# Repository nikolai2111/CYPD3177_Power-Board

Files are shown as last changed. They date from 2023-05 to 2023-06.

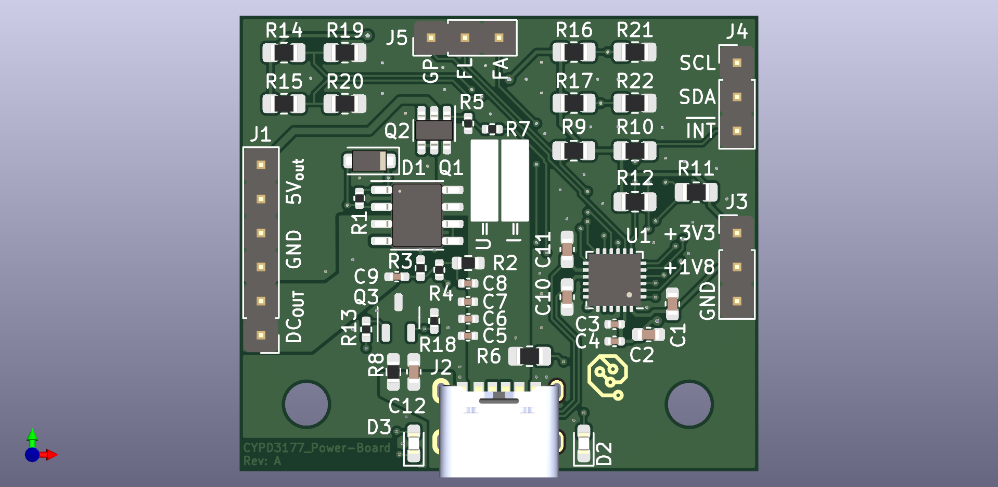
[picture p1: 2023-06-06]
PCB_Top_A.png

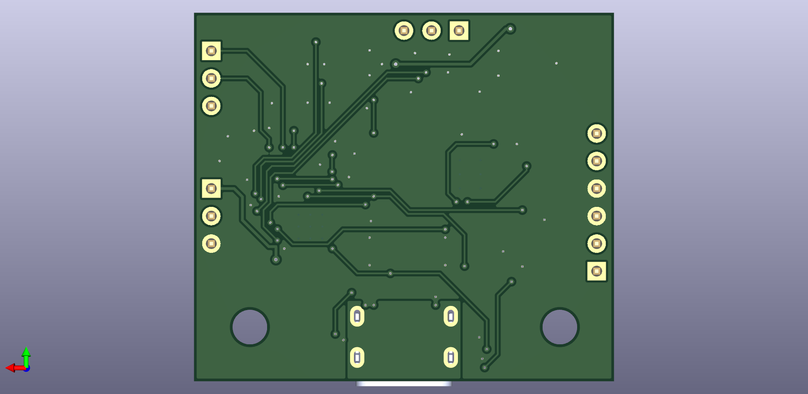
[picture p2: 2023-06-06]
PCB_Bottom_C.png

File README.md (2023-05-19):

# CYPD3177_Power-Board <!-- omit from toc -->

## Content <!-- omit from toc -->
- [1. Description](#1-description)
- [2. Folder structure](#2-folder-structure)
- [3. Usage](#3-usage)
- [4. License](#4-license)

## 1. Description
TBC: Easy to use and programmable power board for powering your electronics with up to 100 watts of power.

## 2. Folder structure
TBC

## 3. Usage
Add instructions and examples here.

## 4. License
The hardware and its documentation is licensed under the CERN-OHL-P licence, which can be found [here](LICENSE).

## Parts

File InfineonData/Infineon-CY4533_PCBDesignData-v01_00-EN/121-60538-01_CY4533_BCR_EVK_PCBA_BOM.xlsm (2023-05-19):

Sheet: Revision History
CYPRESS SEMICONDUCTOR © 2017
Revision | Date | Description | Prepared By | Approved By
1 | 2018-09-17 | First version of CY4533 BOM | KUMR | PDS
 |  |  |  |  | a

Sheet: PCBA BOM
 |  |  |  |  | CYPRESS SEMICONDUCTOR © 2018-2019
 |  |  |  |  | TITLE | CY4533 BCR Evaluation Kit
 |  |  |  |  | PCA Number & Revision | 121-60538-01 | Rev 02
 |  |  |  |  | Schematics Number & Revision | 630-60538-01 | Rev 02
 |  |  |  |  | DATE | 2019-03-27
 |  |  |  |  | BOM REVISION | Rev 03
 |  |  |  |  | ROHS Compliance | Required
 |  |  |  |  | UL Compliance | Required
# | Cypress Part # | Qty | Reference | Value | Description | Manufacturer | Mfr Part # | Alternate Manufacturer | Alternate Mfr Part #
1 |  | 2 | C1,C4 | 1uF | CAP CER 1UF 16V X7R 0603 | KEMET | C0603C105K4RACTU
2 |  | 2 | C2,C3 | 0.1uF | CAP CER 0.1UF 10V X7R 0402 | AVX Corporation | 0402ZC104KAT2A
3 |  | 2 | C5,C6 | 390pF | CAP CER 390PF 50V 5% X7R 0603 | Kemet | C0603C391J5RACTU
4 |  | 1 | C7 | 3.3uF | CAP CER 3.3UF 50V X7R 1210 | KEMET | C1210C335K5RACAUTO
5 |  | 1 | C8 | 1uF | CAP CER 1UF 35V X5R 0402 | Samsung Electro-Mechanics | CL05A105KL5NRNC
6 |  | 1 | D1 | RED | LED RED CLEAR 0603 SMD | Lite-On Inc. | LTST-C190EKT
7 |  | 1 | D2 | GREEN | LED GREENCLEAR 0603 SMD | Lite-On Inc. | LTST-C190GKT
8 |  | 1 | D3 | NZH10C-115 | DIODE ZENER 10V 500MW SOD123F | Nexperia USA Inc. | NZH10C,115
9 |  | 1 | J1 | 8x1 RECP | CONN HEADER .100 SINGL STR 8POS | Sullins Connector Solutions | S9691E-08
10 |  | 1 | J2 | USB-PD_TYPE-C | CU18 USB Type-C Receptacle Connector | CviLux Corporation | CU1816SAH1BA0R001-LF-CUS
11 |  | 1 | J3 | TERMINAL_BLOCK | TERMINAL BLOCK 5MM VERT 2POS PCB | On Shore | OSTTC020162
12 |  | 1 | Q1 | IRF9358TRPBF | MOSFET 2P-CH 30V 9.2A 8SOIC | Infineon Technologies | IRF9358TRPBF
13 |  | 1 | Q3 | BSL308PE | MOSFET 2P-CH 30V 2A 6TSOP | Infineon Technologies | BSL308PEH6327XTSA1
14 |  | 1 | Q4 | NTR4503N | MOSFET N-CH 30V 1.5A SOT-23 | ON Semiconductor | NTR4503NT1G
15 |  | 2 | R1,R8 | 1K | RES SMD 1K OHM 5% 1/10W 0603 | Yageo | RC0603JR-071KL
16 |  | 3 | R3,R6,R13 | 5K | RES SMD 5K OHM 5% 1/10W 0603 | Yageo | RC0603FR-074K99P
17 |  | 1 | R7 | 2.4K | RES SMD 2.4K OHM 5% 1/10W 0603 | Panasonic Electronic Components | ERJ-3GEYJ242V
18 |  | 2 | R12,R14 | 10K | RES SMD 10K OHM 1% 1/10W 0603 | Panasonic Electronic Components | ERJ-3EKF1002V
19 |  | 1 | R15 | 0OHM | RES SMD 0 OHM JUMPER 1/16W 0402 | Yageo | RC0402FR-070RL
20 |  | 2 | R16,R22 | 1K | RES 1K OHM 5% 1/16W 0402 | Samsung Electro-Mechanics America, Inc | RCS1005J102CS
21 |  | 1 | R17 | 2.2K | RES SMD 2.2K OHM 5% 1/2W 0805 | Panasonic Electronic Components | ERJ-P6WJ222V
22 |  | 2 | R19,R24 | 49.9K | RES SMD 49.9K OHM 1% 1/10W 0402 | Panasonic Electronic Components | ERJ-2RKF4992X
23 |  | 1 | R20 | 100K | RES SMD 100K OHM 5% 1/2W 0805 | Panasonic Electronic Components | ERJ-P6WJ104V
24 |  | 1 | R21 | 10K | RES SMD 10K OHM 5% 1/16W 0402 | Yageo | RC0402JR-0710KL
25 |  | 4 | R25,R26,R27,R28 | 2K | RES SMD 2K OHM 5% 1/16W 0402 | Yageo | RC0402JR-072KL
26 |  | 1 | SW1 | SW_SL_SP5T | SWITCH ROTARY DIP SP5T 100MA 5V | Nidec Copal Electronics | SS-10-15SPE
27 |  | 5 | TP3,TP6,TP7,TP8,TP9 | TP | SMD TEST POINT |  | TEST PAD
28 |  | 2 | TP4,TP13 | TP | SMD TEST POINT
29 |  | 1 | TP10 | BLACK | TEST POINT PC MINI .040"D BLACK | Keystone Electronics | 5001
30 |  | 2 | TP11,TP12 | RED | TEST POINT PC MINI .040"D RED | Keystone Electronics | 5000
31 |  | 1 | U1 | CYPD3177-24LQXQ | USB Type-C Port Controller | Cypress Semiconductor | CYPD3177-24LQXQ
NO LOAD
32 |  | 1 | C9 | 1uF_NL | CAP CER 1UF 35V X5R 0402 | TDK Corporation | C1005X5R1V105K050BC
33 |  | 2 | R4,R5 | 10K_NL | RES SMD 10K OHM 1% 1/10W 0603 | Yageo | RC0603FR-0710KL
34 |  | 2 | R10,R11 | 5K_NL | RES SMD 5K OHM 5% 1/10W 0603 | Yageo | RC0603FR-074K99P
ACCESSORIES
35 |  | 2 | ACC8,ACC9 | BS25BL07X30RP | BUMPER HEMI .25" DIA X .08" BLK | Bumper Specialties Inc. | BS25BL07X30RP
 |  |  |  |  |  |  |  |  |  | NO LOAD
 |  |  |  |  |  |  |  |  |  | NO LOAD
 |  |  |  |  |  |  |  |  |  | NO LOAD

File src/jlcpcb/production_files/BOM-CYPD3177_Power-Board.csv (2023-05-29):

Comment | Designator | Footprint | LCSC
1M | R8 | R_0603_1608Metric_Pad0.98x0.95mm_HandSolder | C105578
4.7nF | C12 | C_0603_1608Metric_Pad1.08x0.95mm_HandSolder | C106218
1kΩ | R13,R4,R7 | R_0402_1005Metric_Pad0.72x0.64mm_HandSolder | C106235
2.2kΩ | R10,R11,R12,R20,R22,R6,R9 | R_0805_2012Metric_Pad1.20x1.40mm_HandSolder | C114561
LTST-C190GKT | D2 | LED_0603_1608Metric_Pad1.05x0.95mm_HandSolder | C125093
IRF9358PbF | Q1 | HSOP-8-1EP_3.9x4.9mm_P1.27mm_EP2.41x3.1mm_ThermalVias | C150907
390pF | C10,C11 | C_0603_1608Metric_Pad1.08x0.95mm_HandSolder | C1617
10kΩ | R2 | R_0603_1608Metric | C234237
CYPD3177-24LQXQx | U1 | QFN-24-1EP_4x4mm_P0.5mm_EP2.7x2.7mm_ThermalVias | C2959321
1µF | C5,C6,C7,C8,C9 | C_0402_1005Metric | C307413
0.1µF | C3,C4 | C_0402_1005Metric | C309458
USB4125-GF-A | J2 | GCT_USB4125-GF-A | C3151650
BSL308PE | Q2 | SOT-23-6 | C3289349
LTST-C190EKT | D3 | LED_0603_1608Metric_Pad1.05x0.95mm_HandSolder | C364560
49.9kΩ | R1,R18,R5 | R_0402_1005Metric | C409918
NTR4503N | Q3 | SOT-23-3 | C5236683
NZH10C,115 | D1 | D_SOD-123F | C551630
1µF | C1,C2 | C_0603_1608Metric | C59782
0Ω | R3 | R_0402_1005Metric_Pad0.72x0.64mm_HandSolder | C60490
5.1kΩ | R14,R15,R16,R17,R19,R21 | R_0805_2012Metric_Pad1.20x1.40mm_HandSolder | C84375
Conn_01x06 | J1 | PinHeader_1x06_P2.54mm_Vertical
Conn_01x03 | J3 | PinHeader_1x03_P2.54mm_Vertical
Conn_01x03 | J4 | PinHeader_1x03_P2.54mm_Vertical
Conn_01x03 | J5 | PinHeader_1x03_P2.54mm_Vertical

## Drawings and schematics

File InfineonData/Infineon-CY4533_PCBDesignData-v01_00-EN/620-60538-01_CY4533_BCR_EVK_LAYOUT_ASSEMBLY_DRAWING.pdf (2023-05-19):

## ART FILM - 14_TOPASSEMBLY

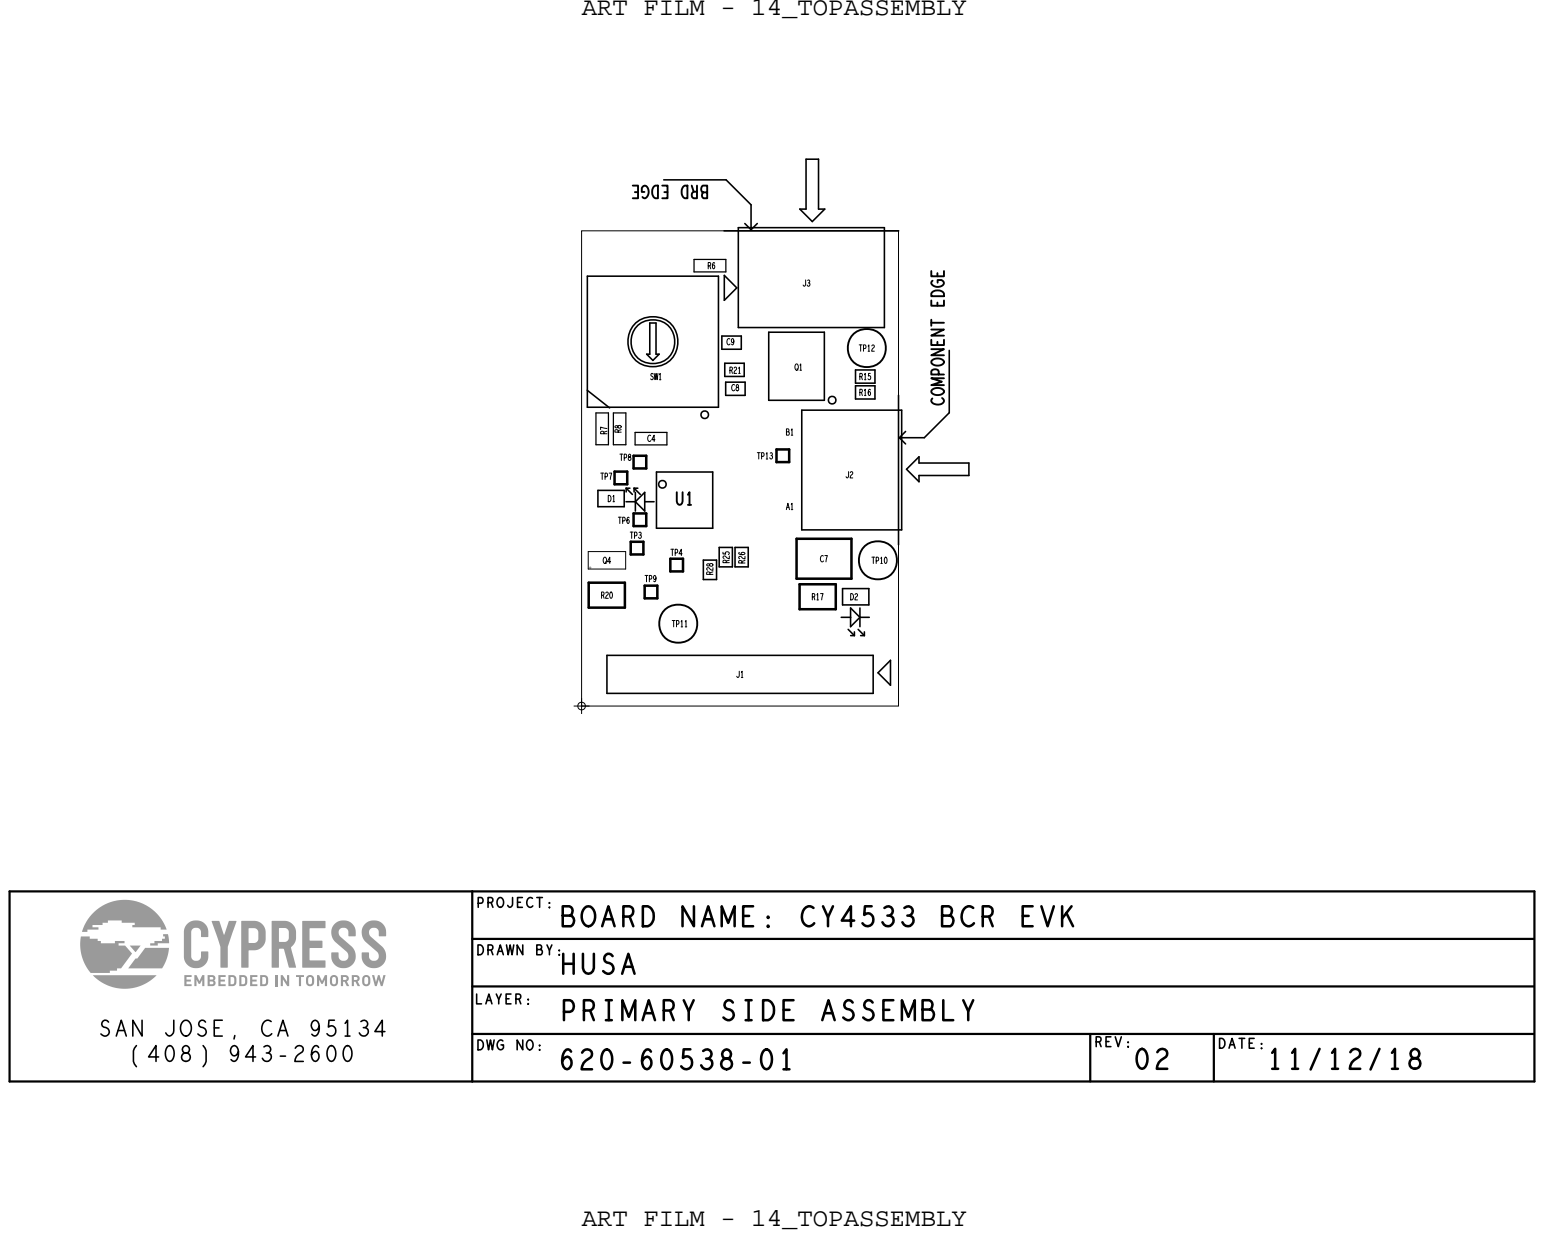
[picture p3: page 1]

R21 | R15
C8 | R16

PRIMARY SIDE ASSEMBLY
DWG NO: 620-60538-01 | REV: 02 | DATE: 11/12/18

## ART FILM - 15_BOTASSEMBLY

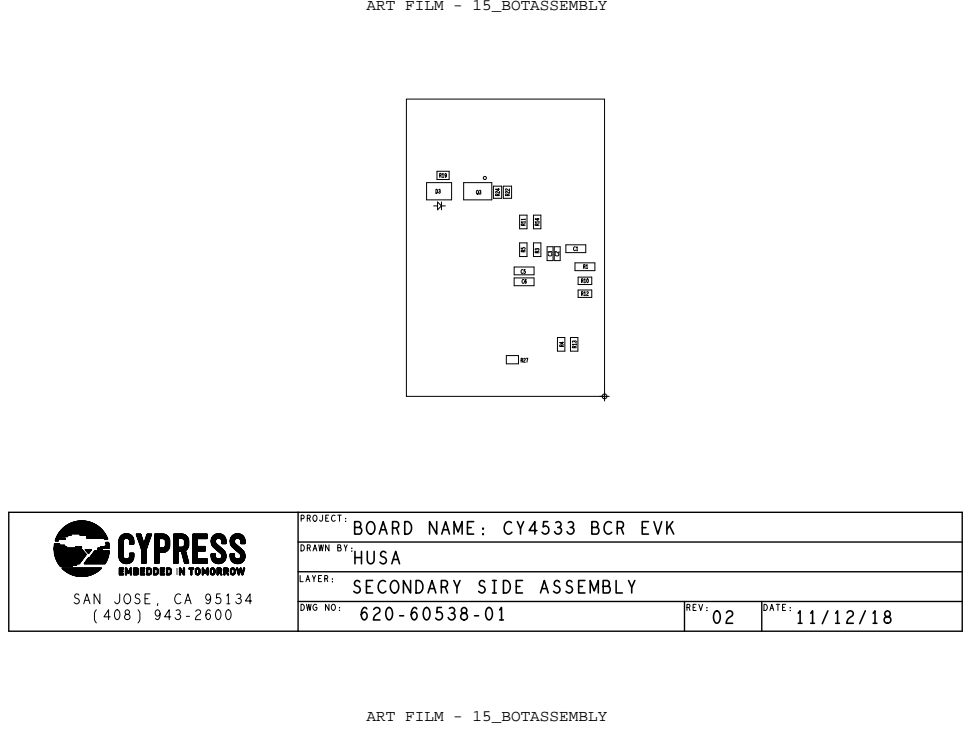
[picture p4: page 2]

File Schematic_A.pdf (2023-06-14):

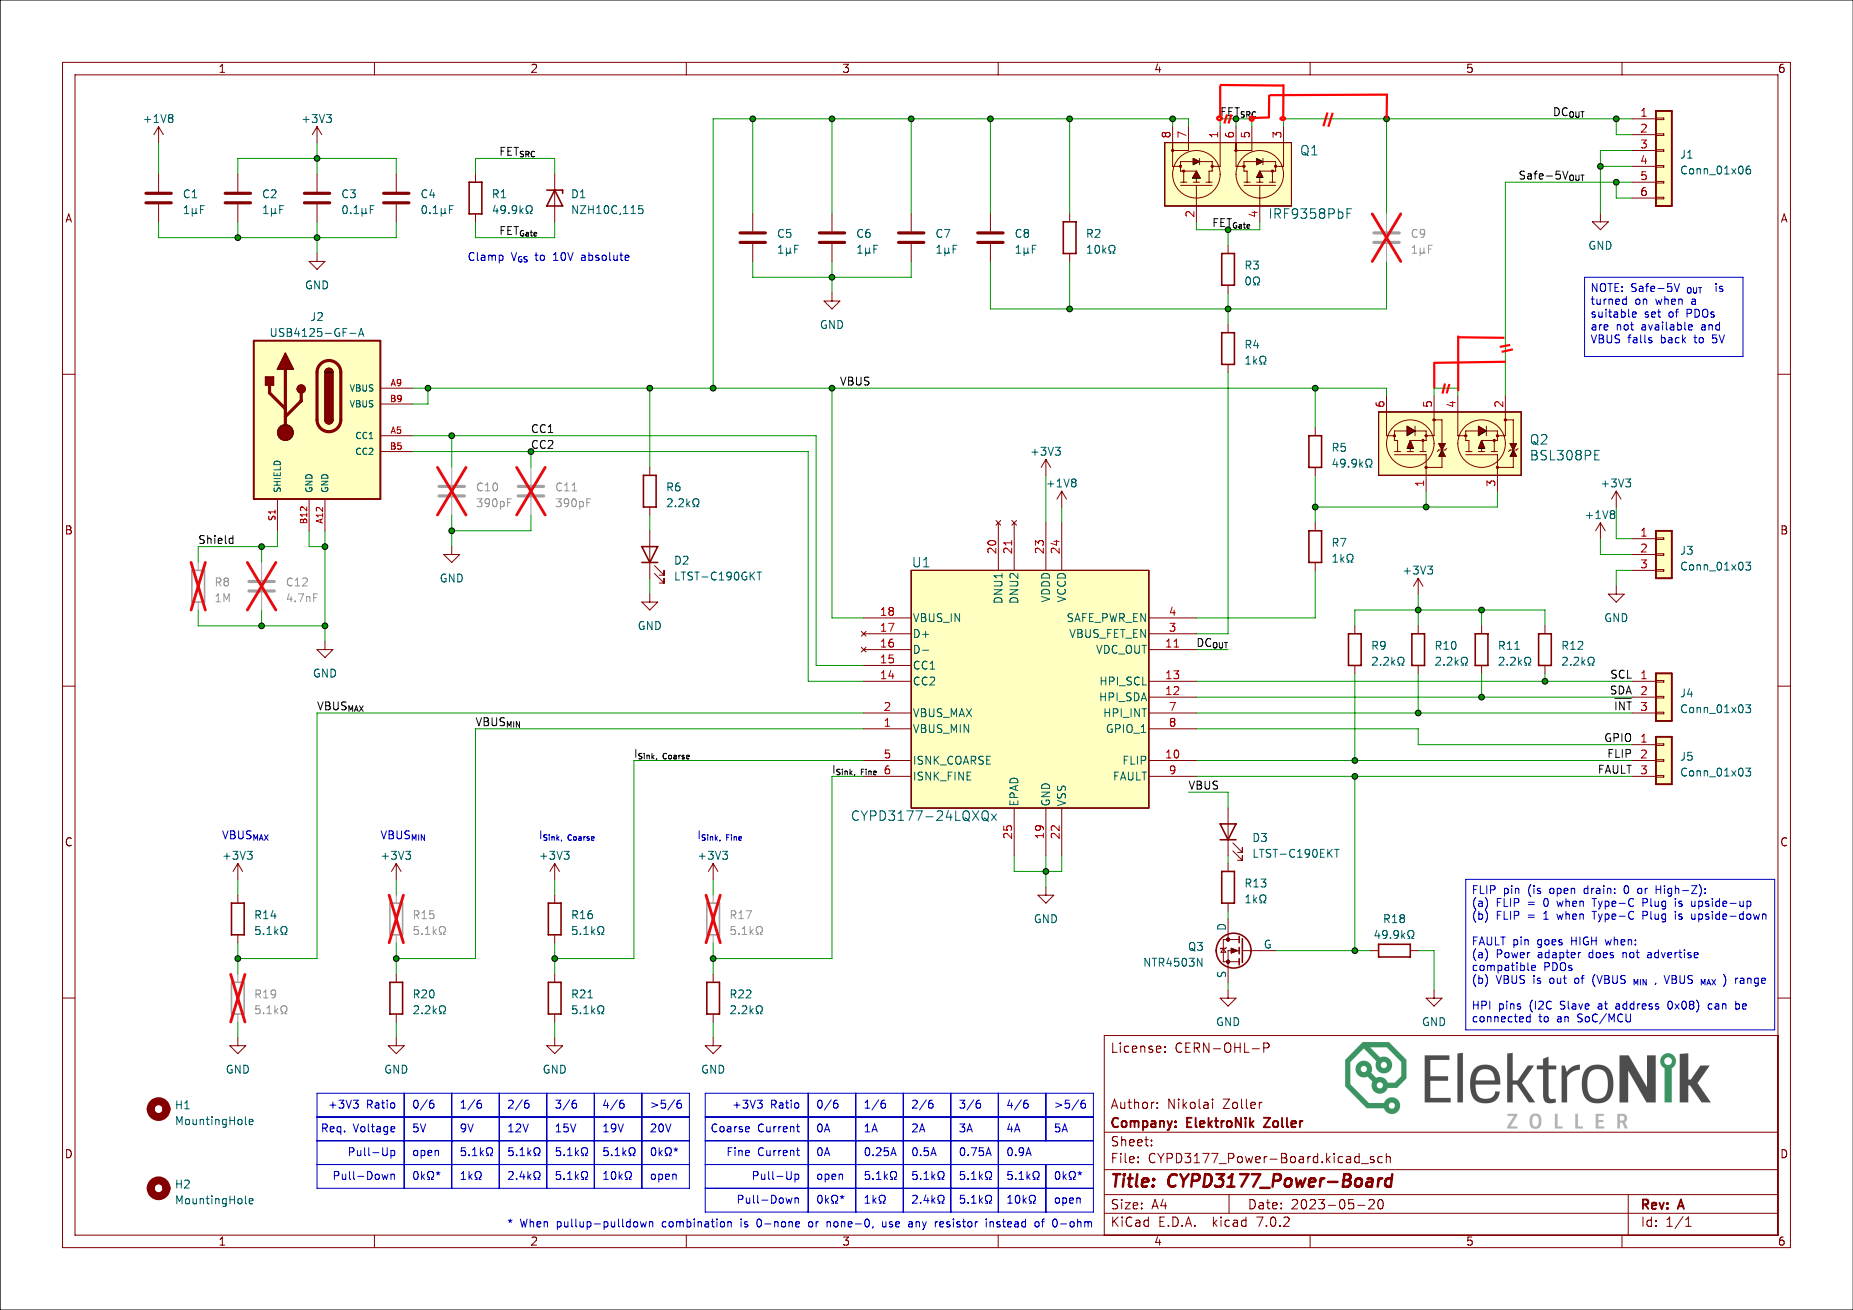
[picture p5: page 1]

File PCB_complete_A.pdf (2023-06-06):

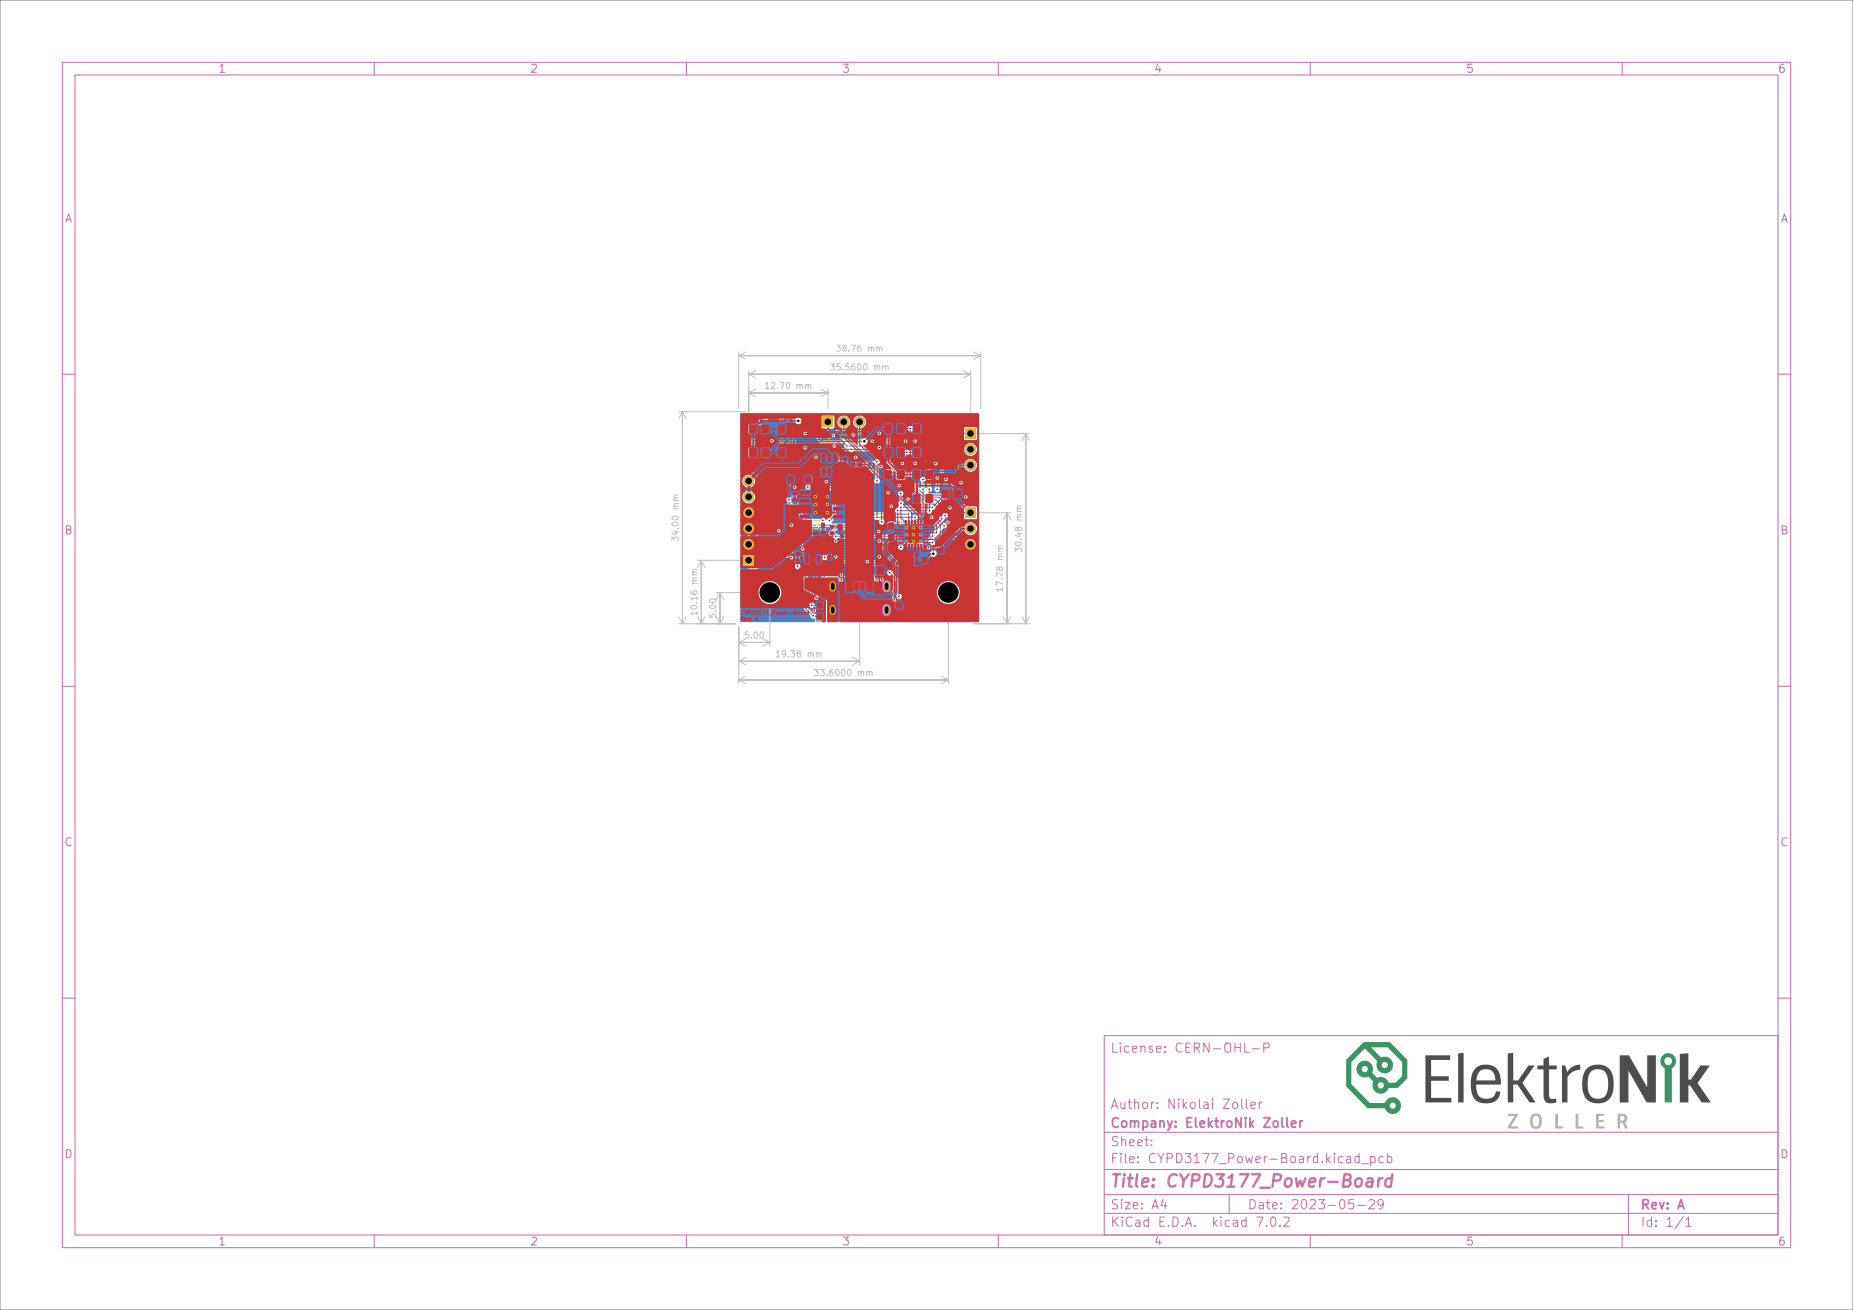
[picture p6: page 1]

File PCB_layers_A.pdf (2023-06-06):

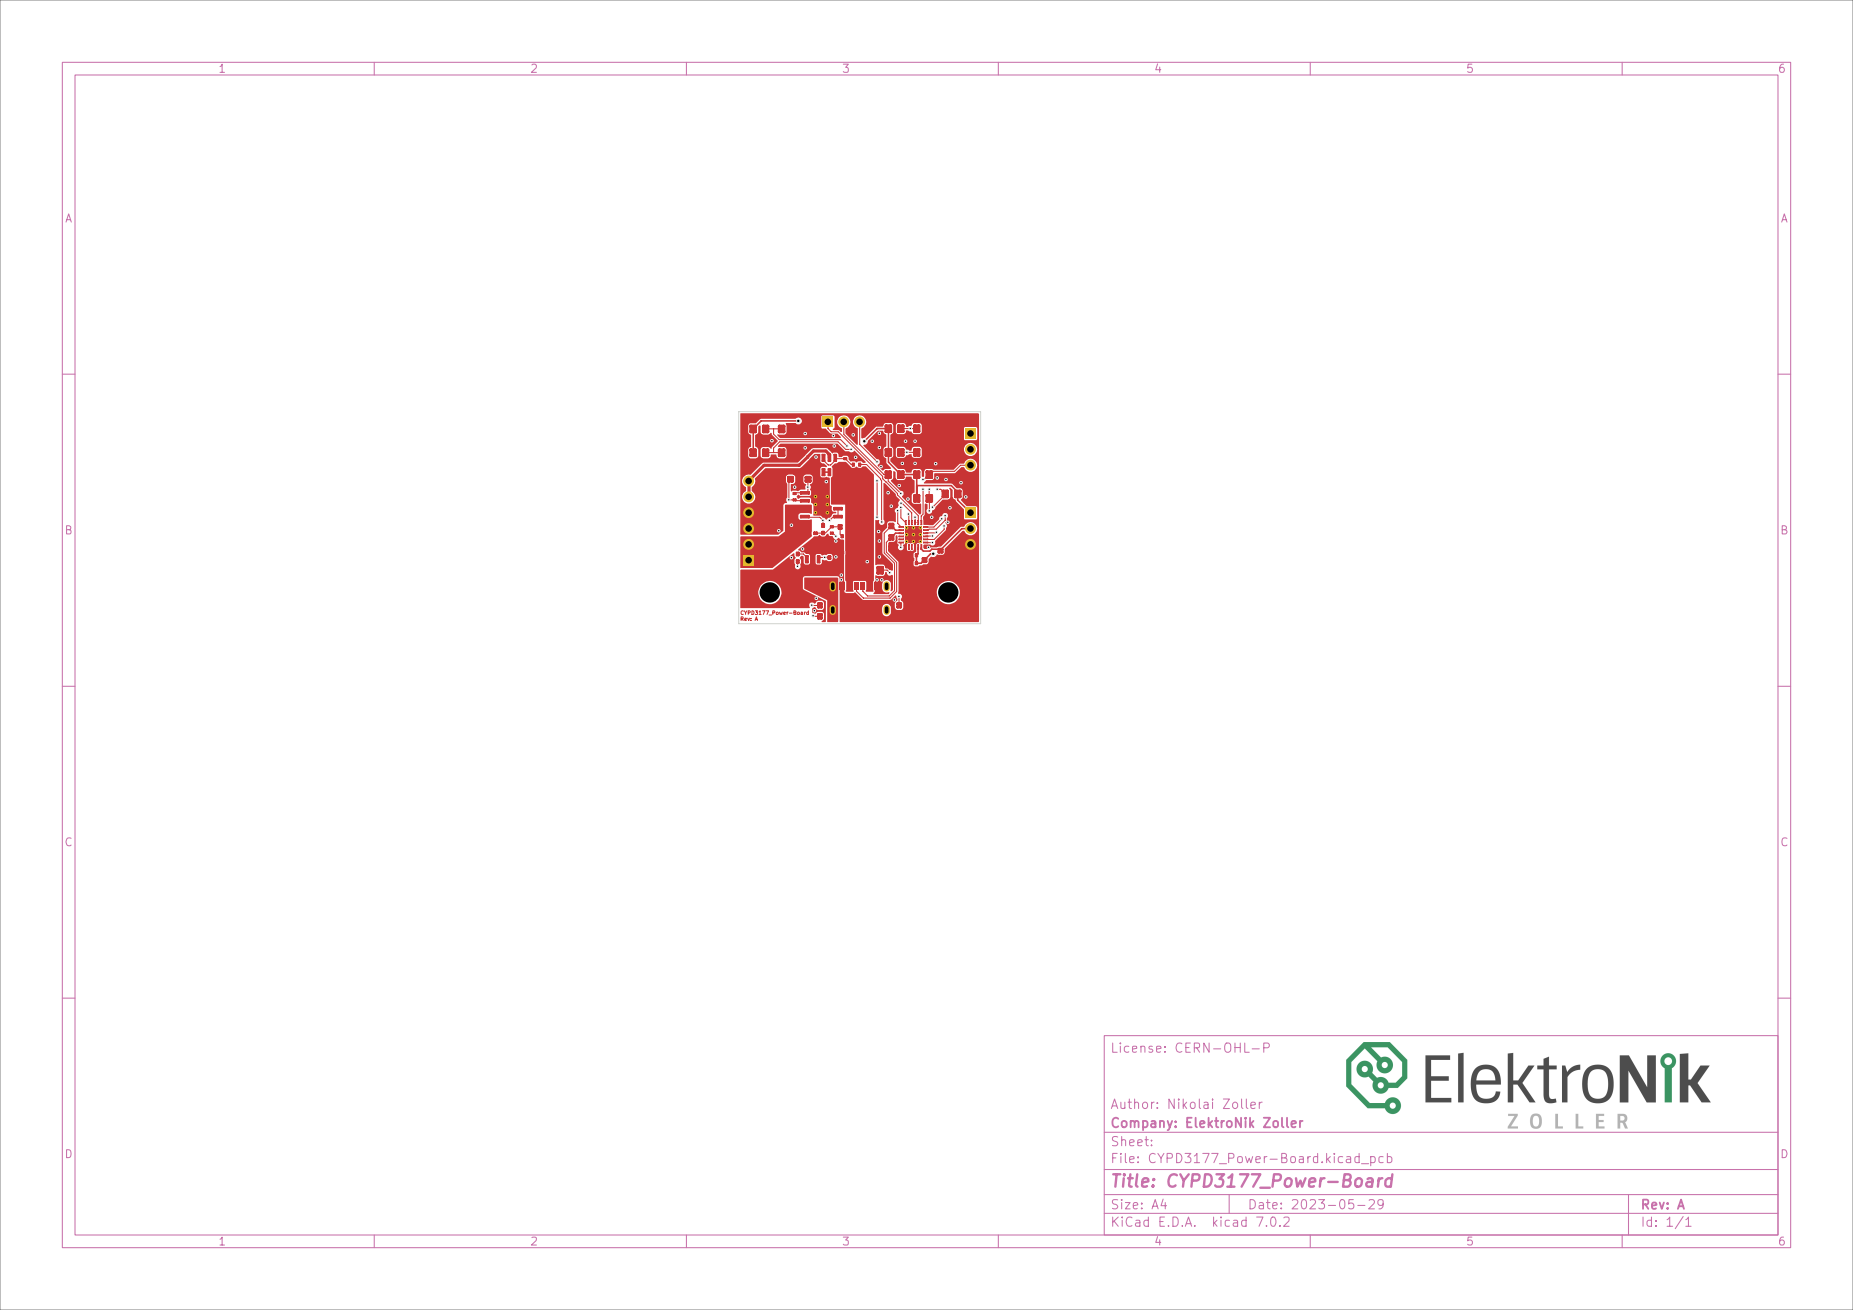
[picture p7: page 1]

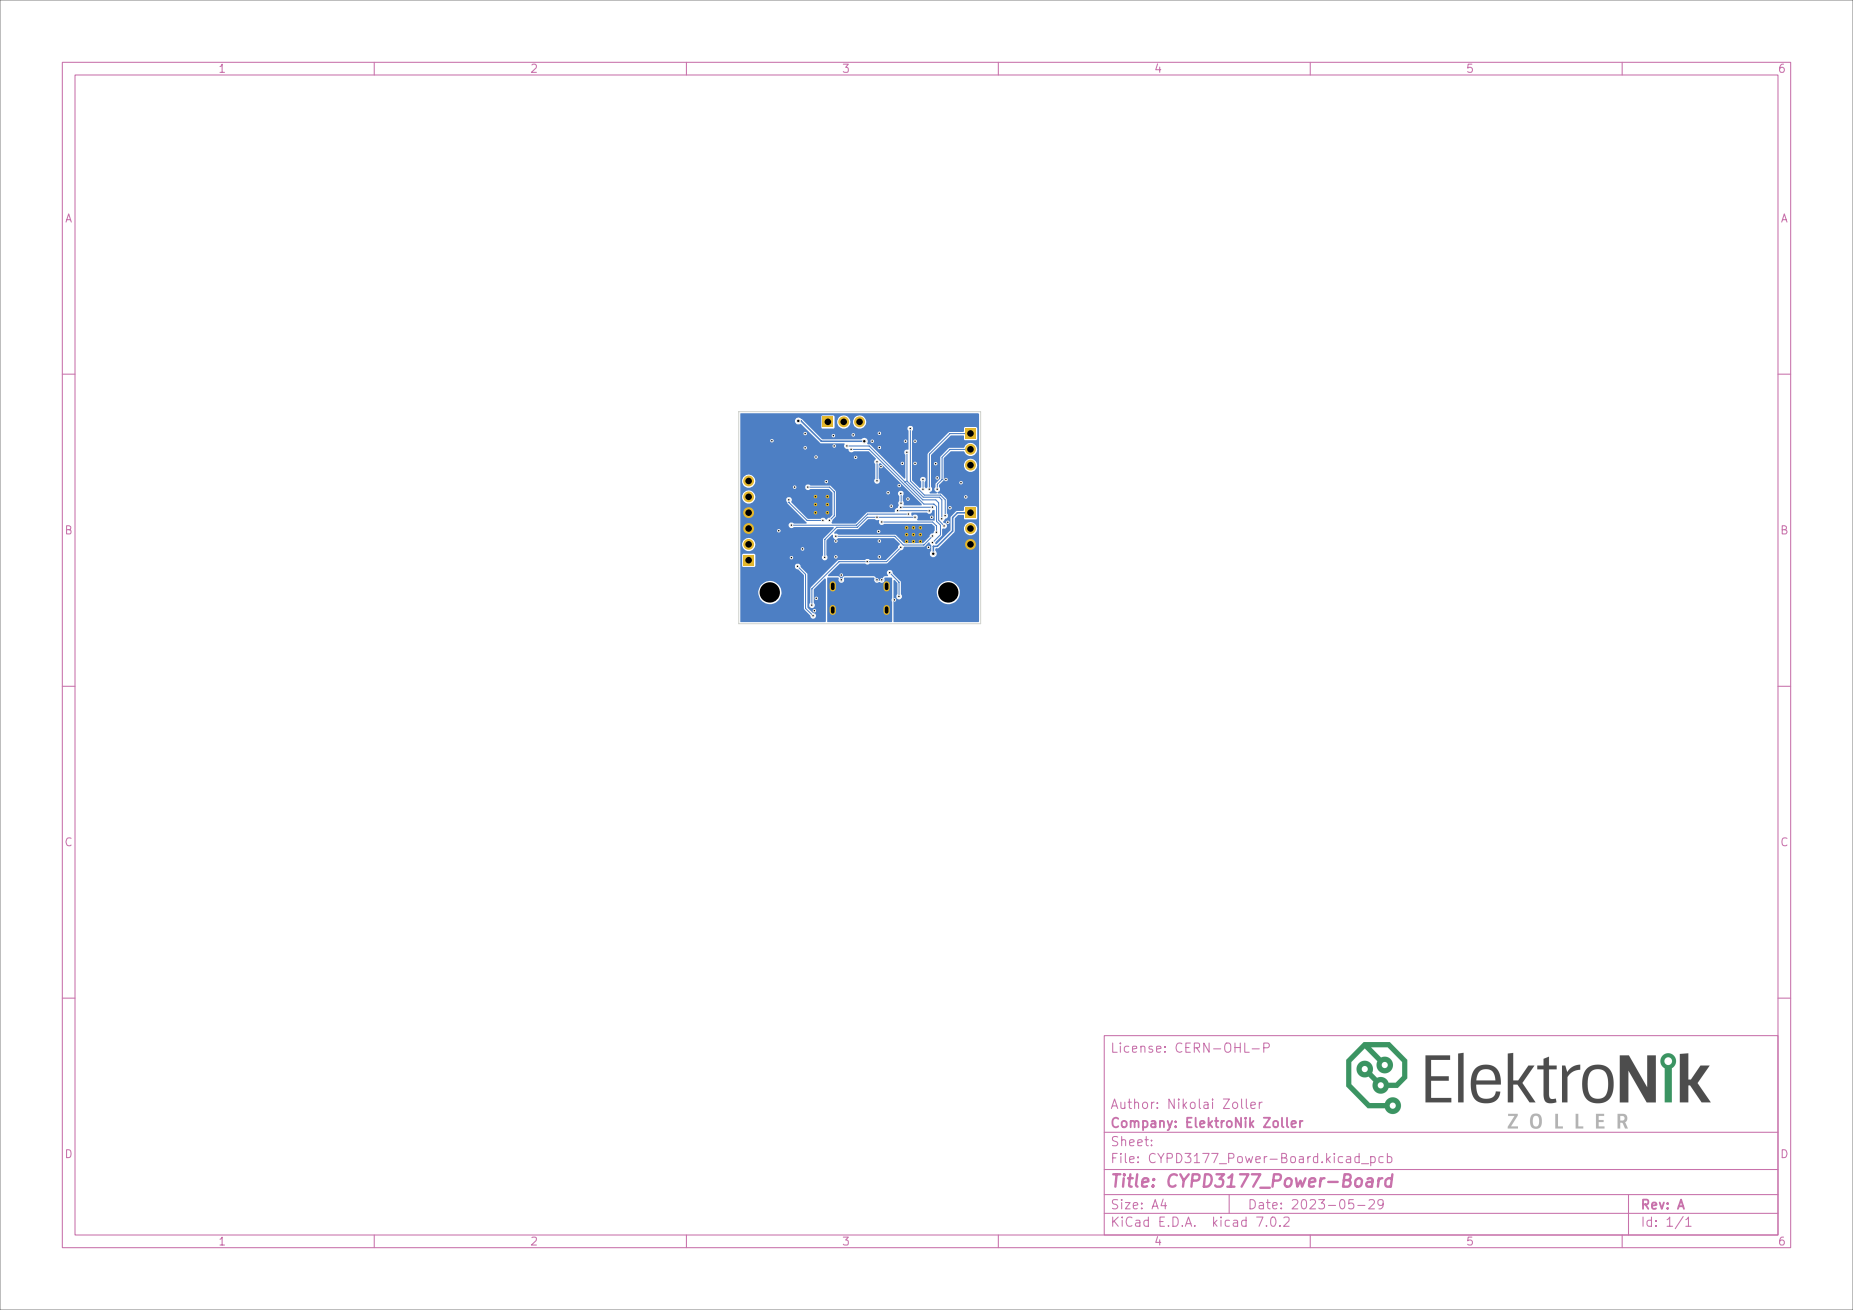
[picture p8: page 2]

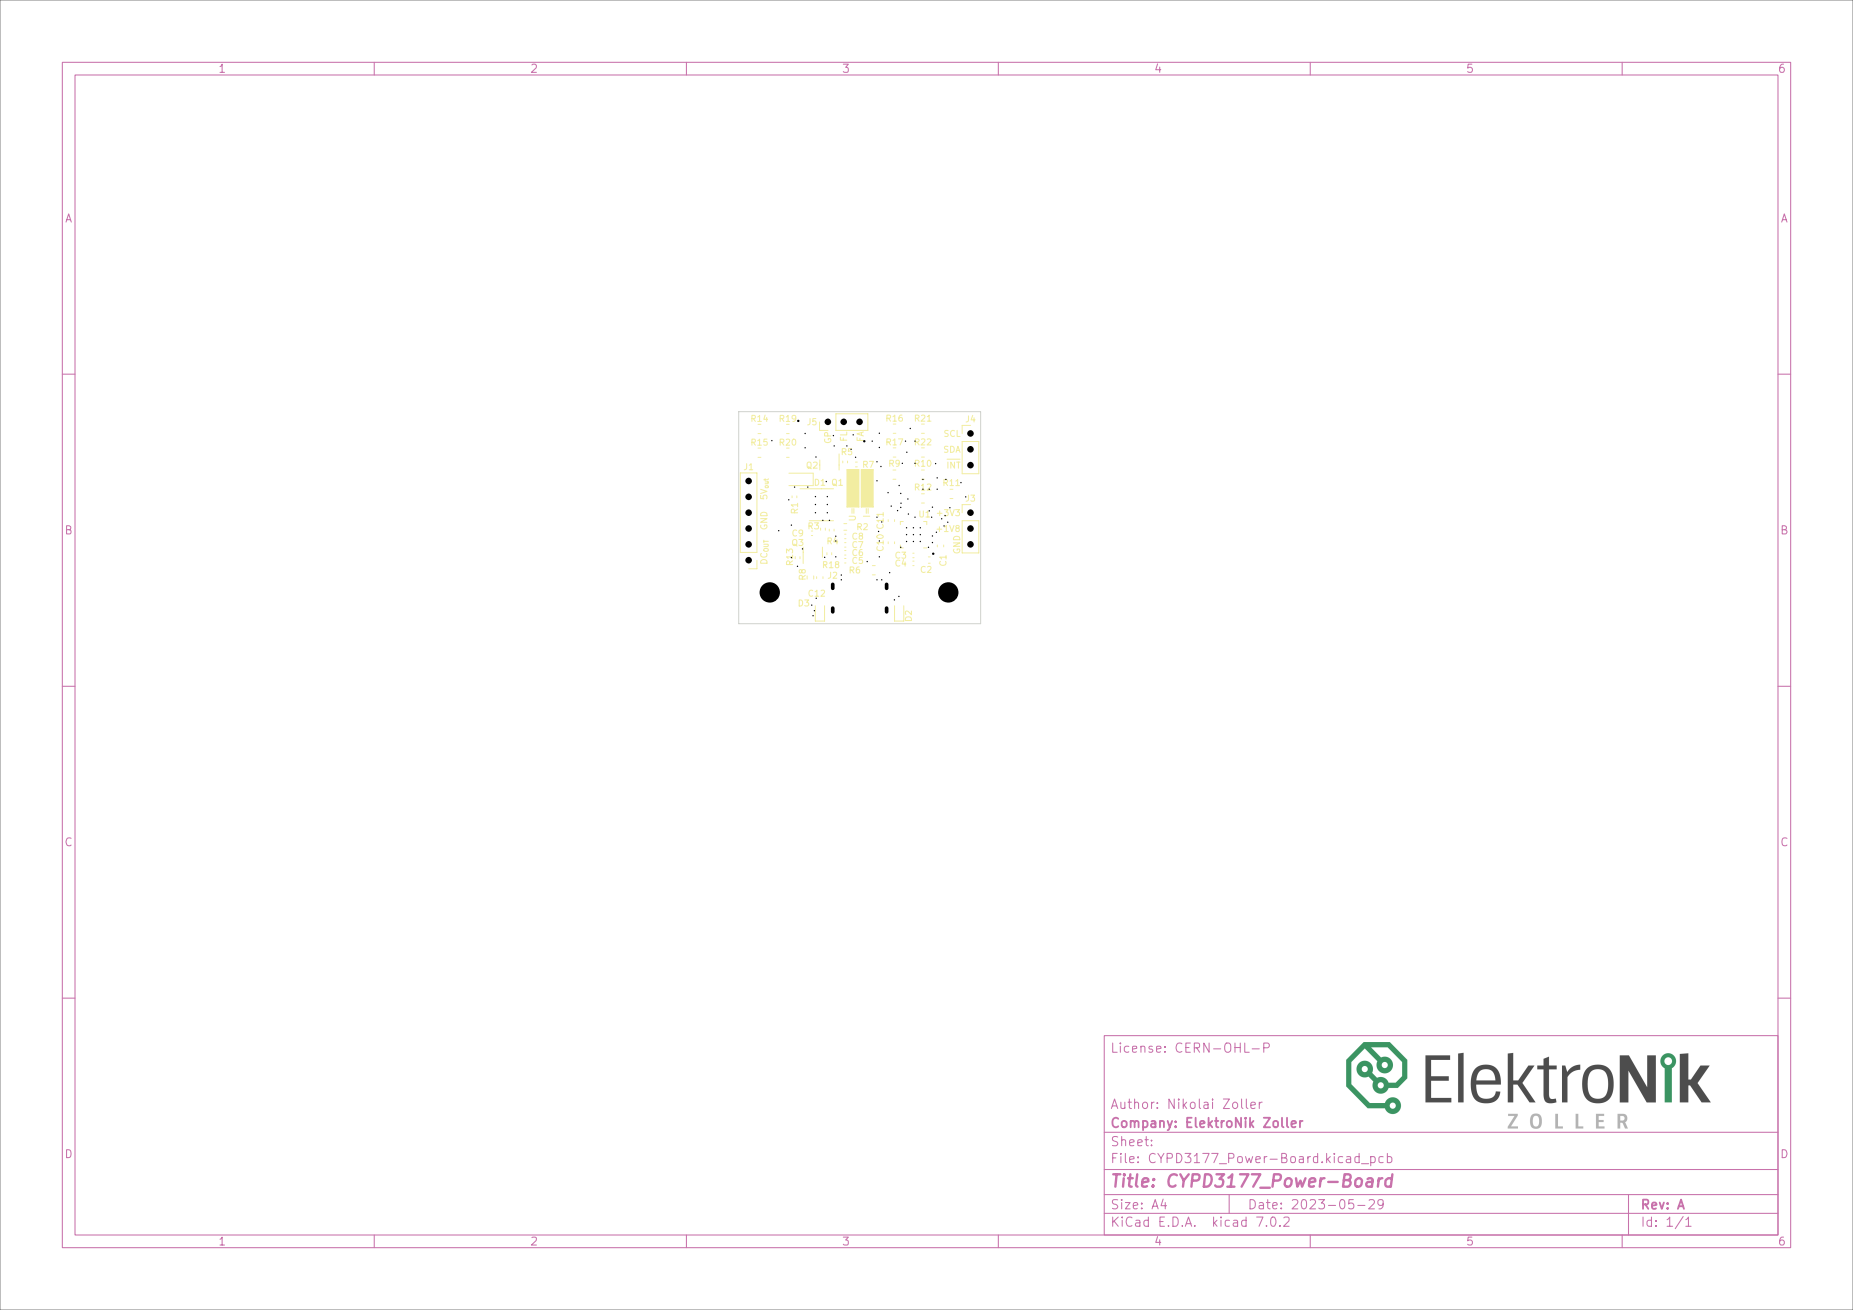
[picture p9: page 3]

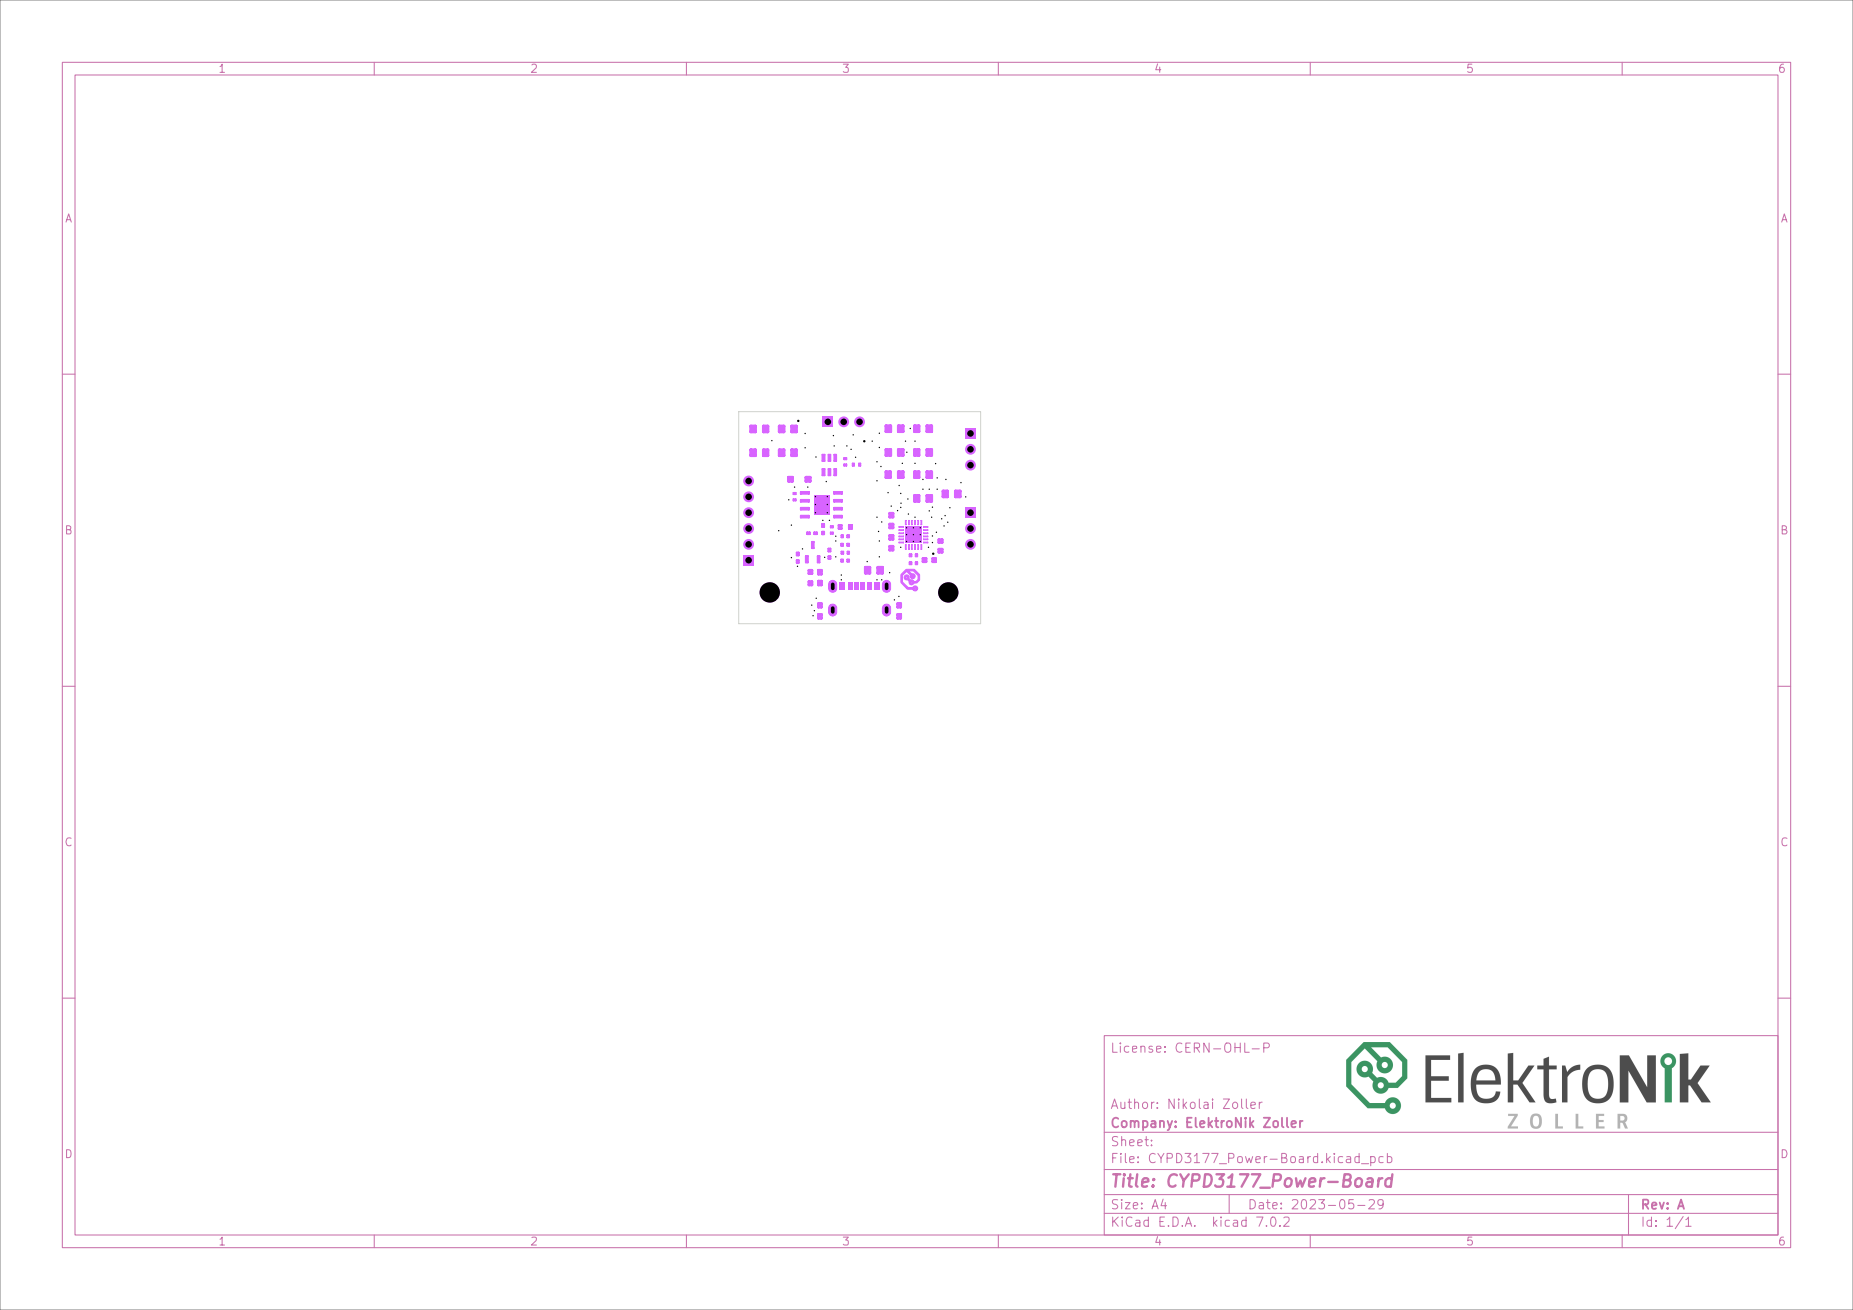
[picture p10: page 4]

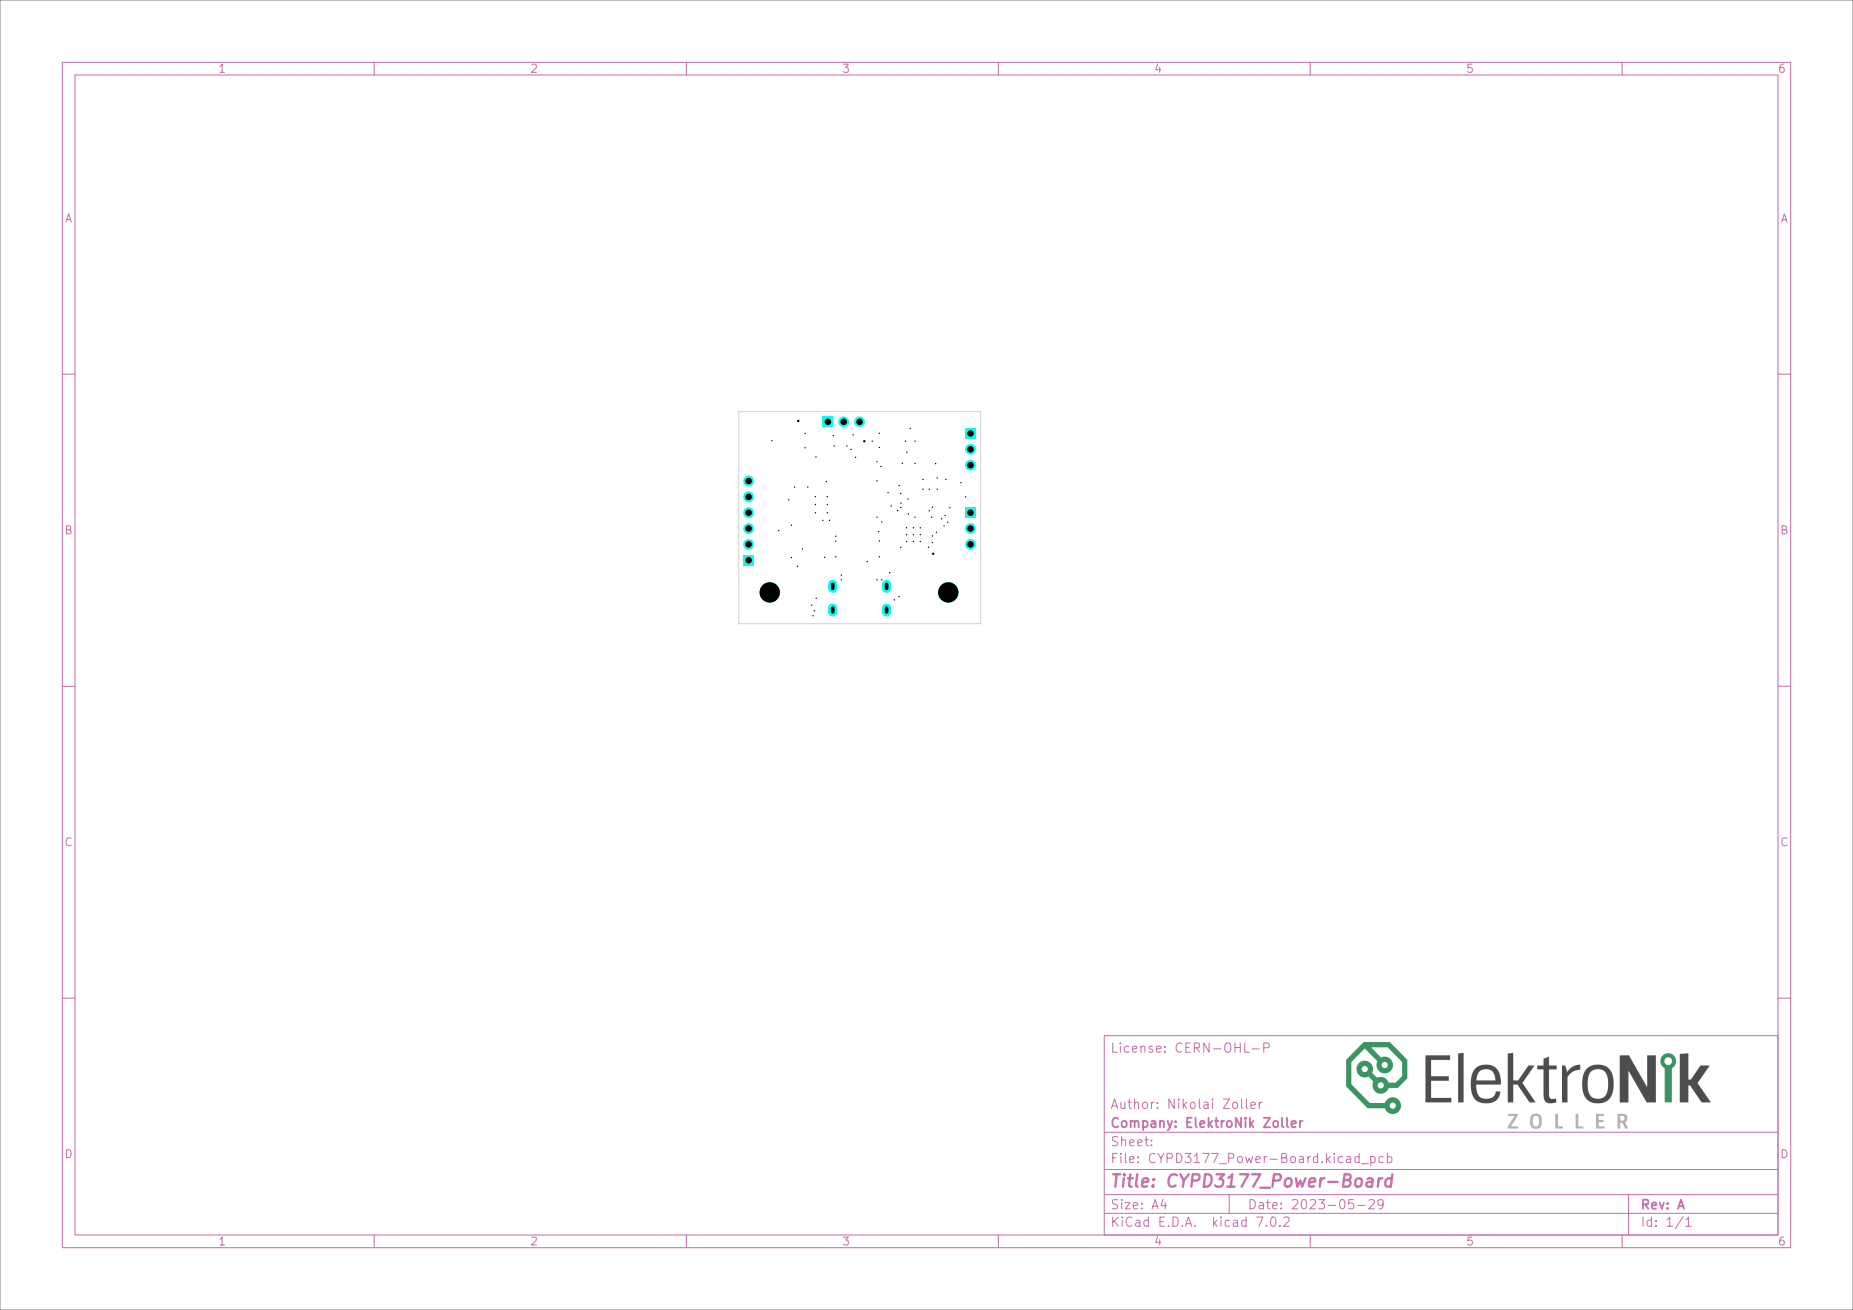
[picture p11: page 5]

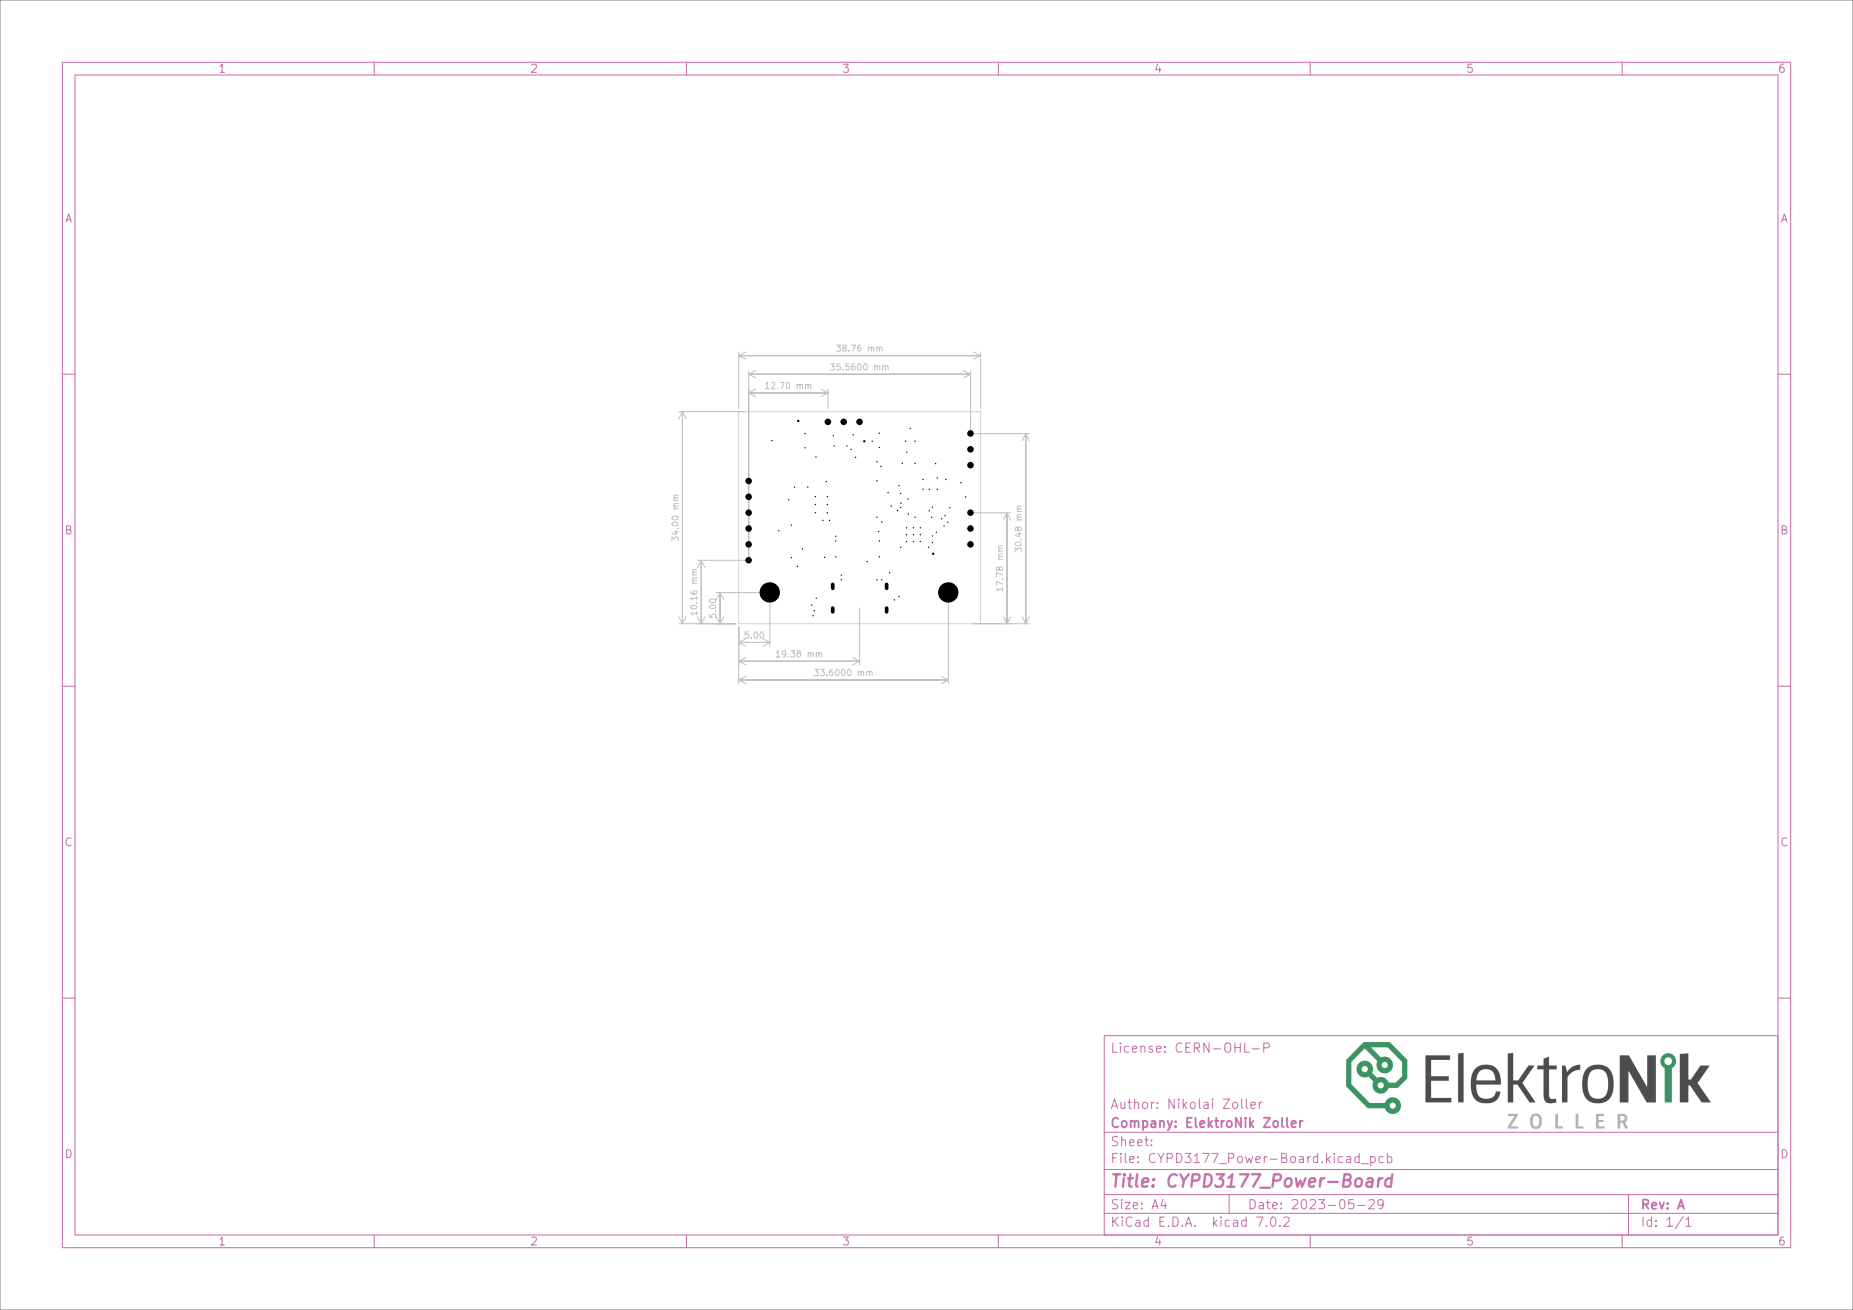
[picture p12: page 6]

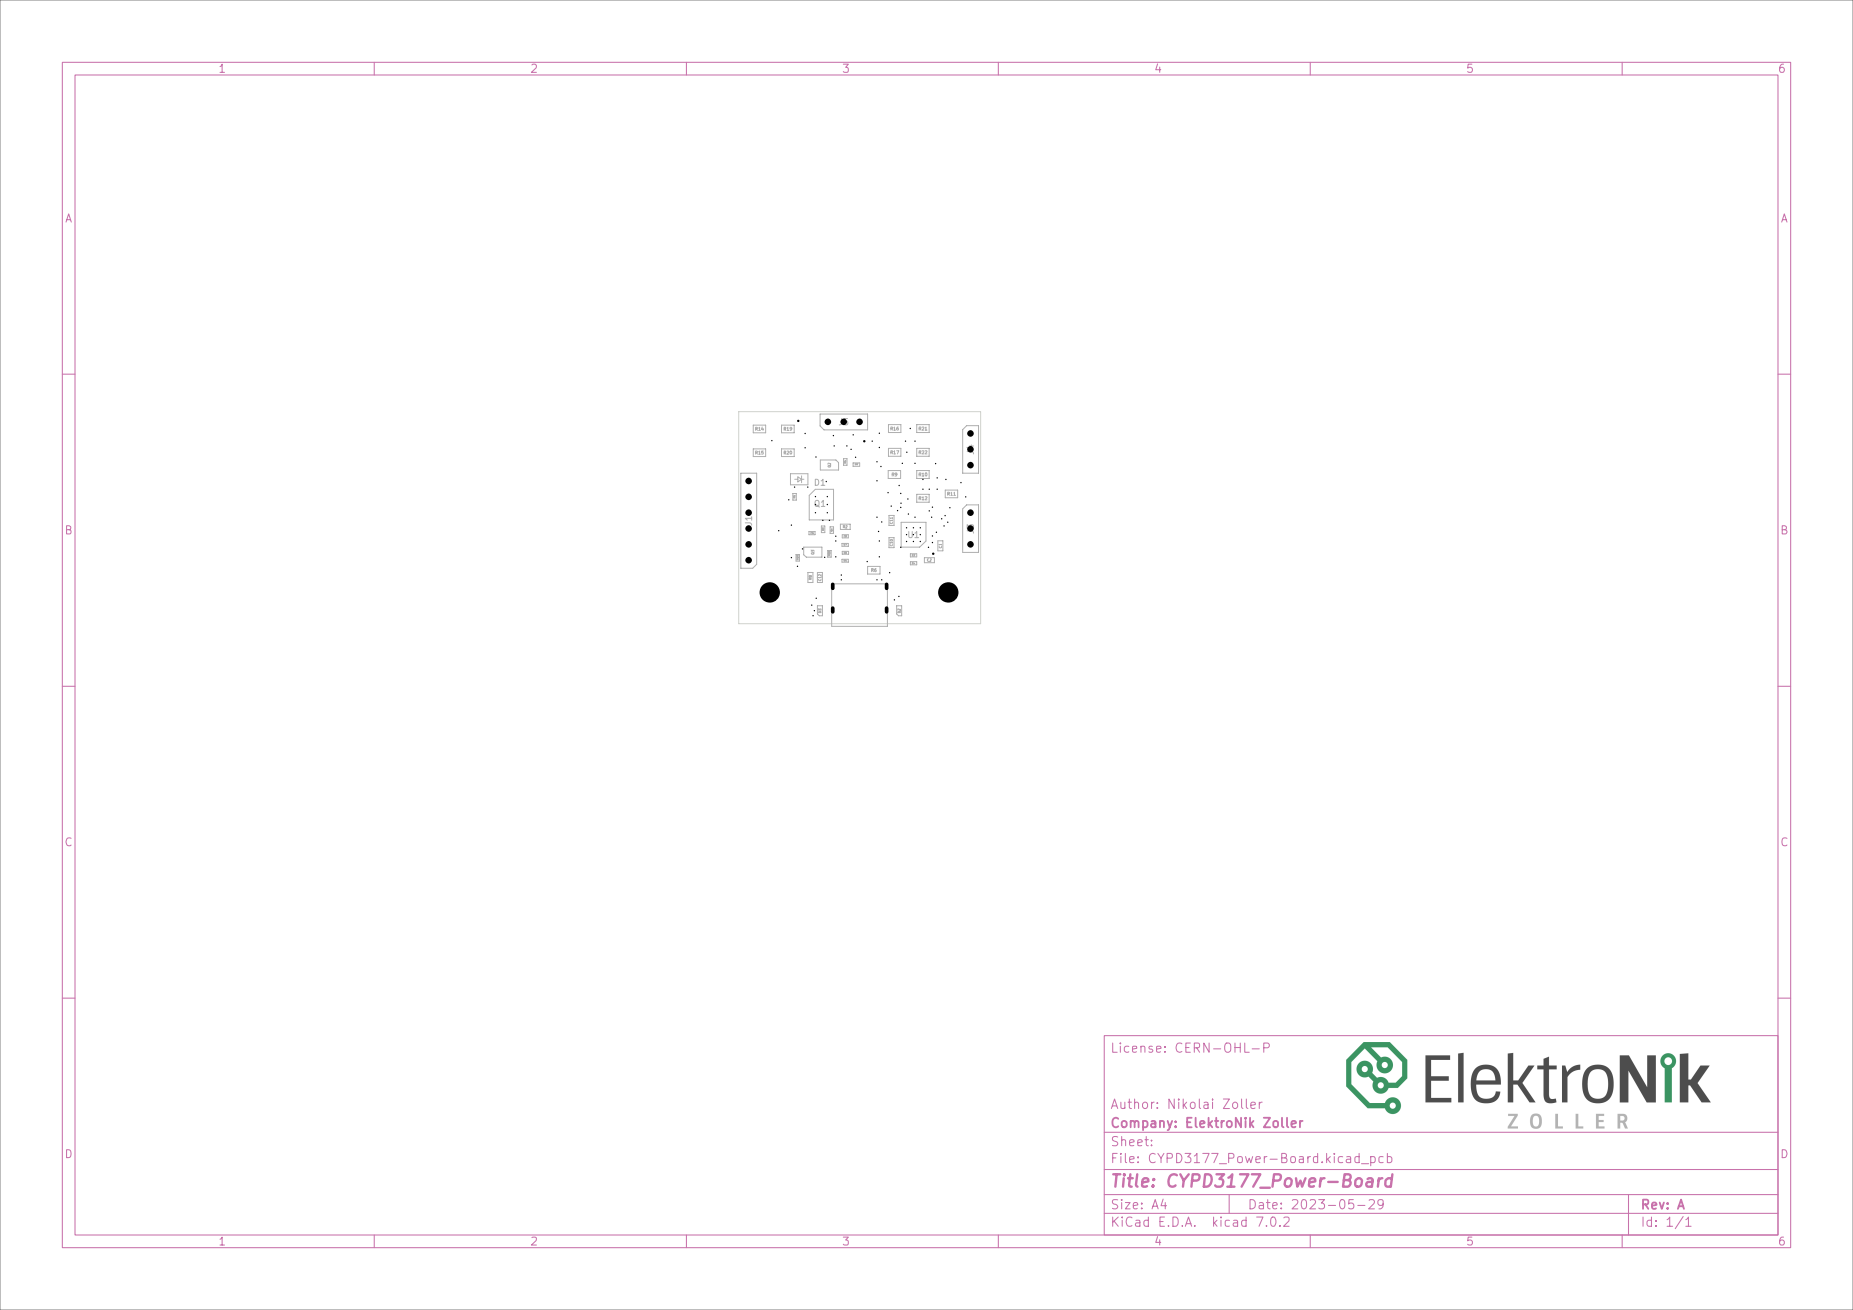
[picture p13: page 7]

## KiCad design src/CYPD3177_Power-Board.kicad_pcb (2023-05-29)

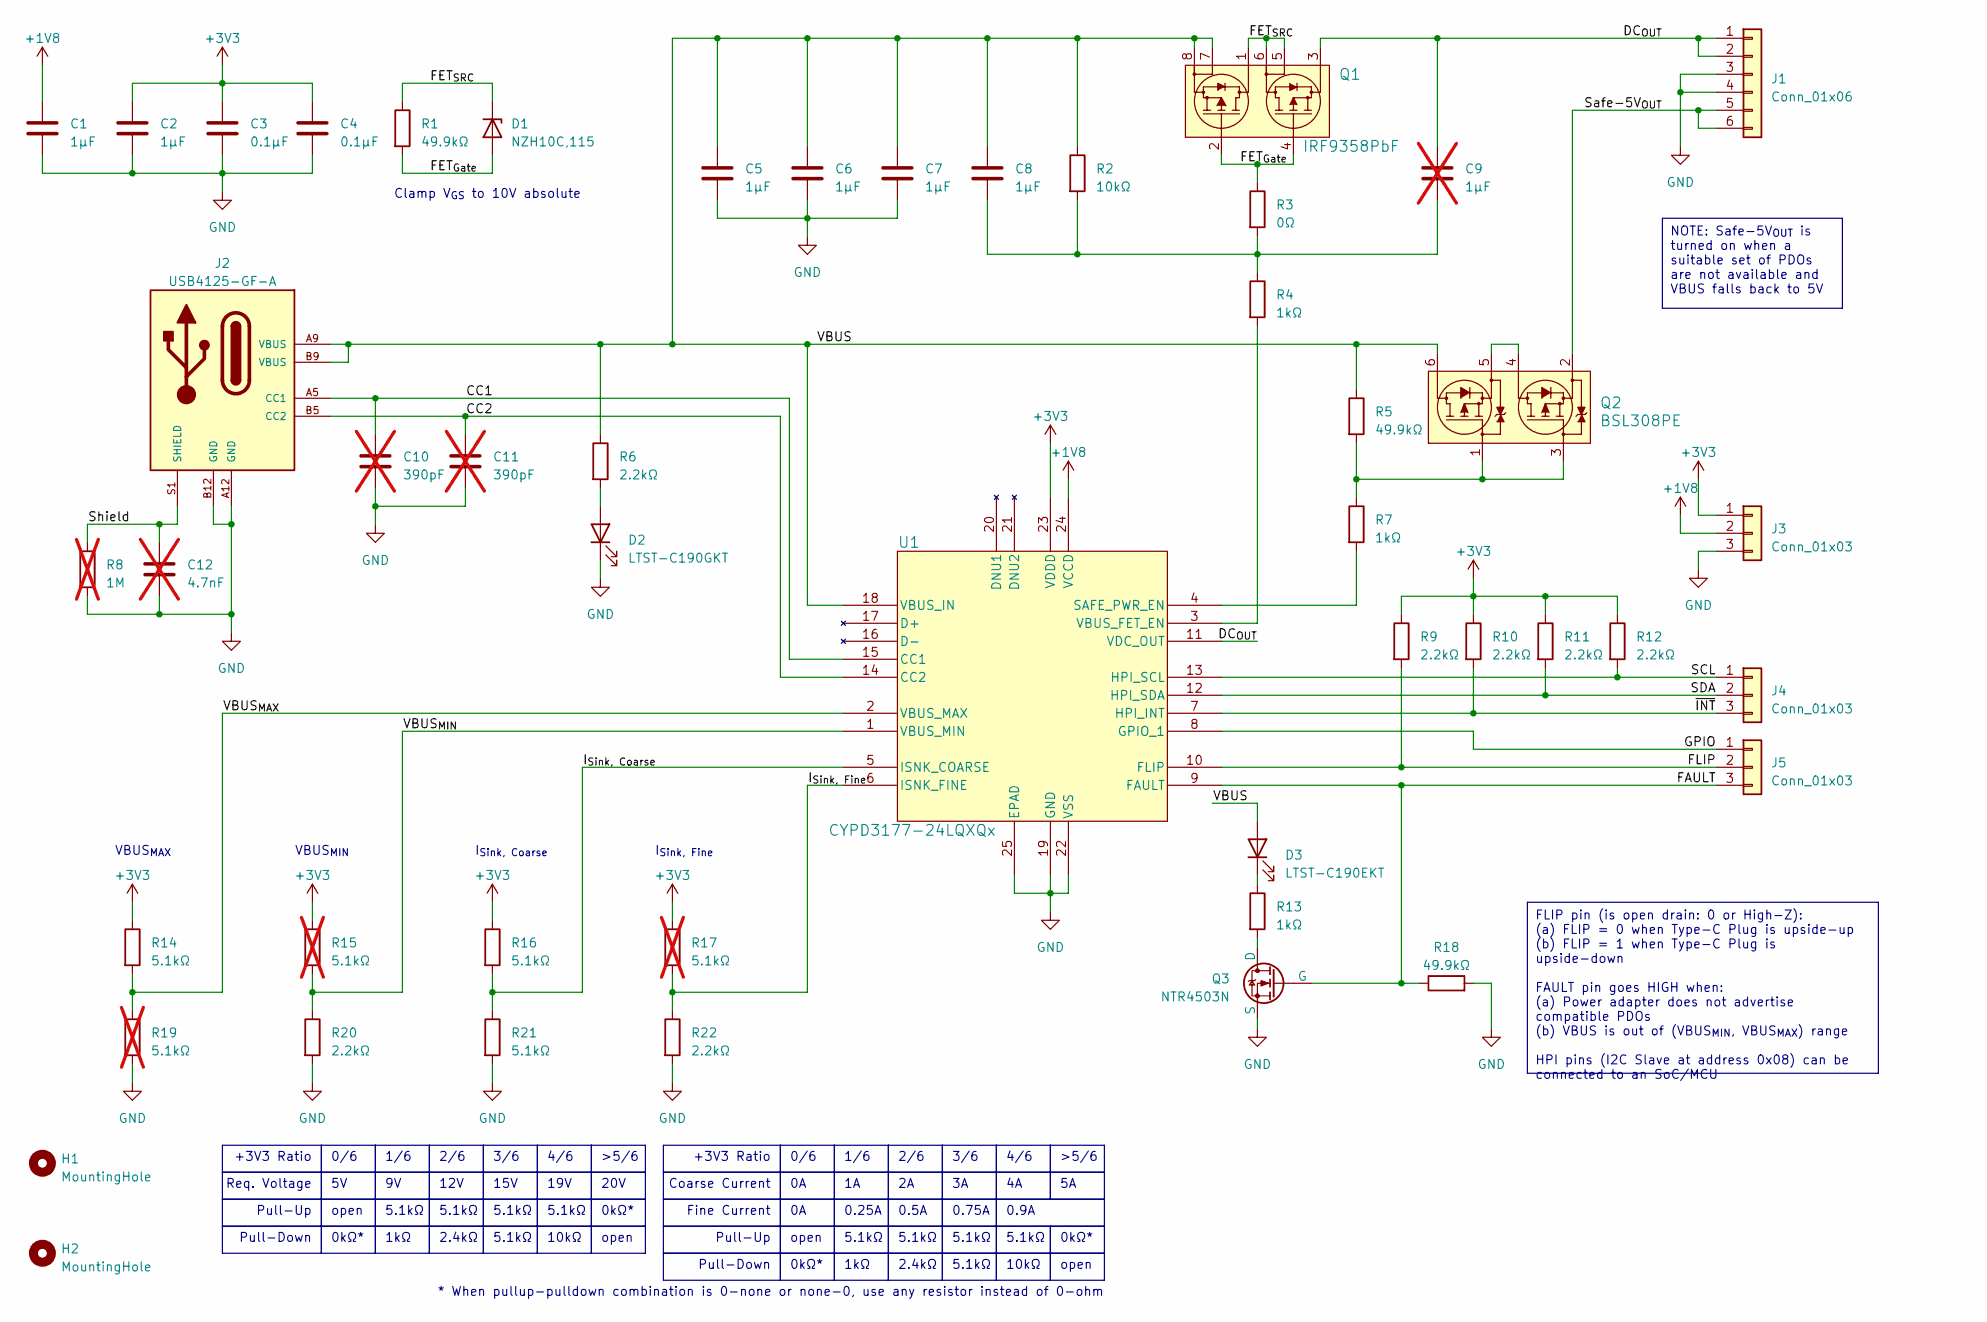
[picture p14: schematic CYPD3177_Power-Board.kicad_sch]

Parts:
C1, C2: 1µF; C_0603_1608Metric
C3, C4: 0.1µF; C_0402_1005Metric
C5, C6, C7, C8: 1µF; C_0402_1005Metric
C9: 1µF; C_0402_1005Metric_Pad0.74x0.62mm_HandSolder; not fitted
C10, C11: 390pF; C_0603_1608Metric_Pad1.08x0.95mm_HandSolder; not fitted
C12: 4.7nF; C_0603_1608Metric_Pad1.08x0.95mm_HandSolder; not fitted
D1: NZH10C,115; D_SOD-123F
D2: LTST-C190GKT; LED_0603_1608Metric_Pad1.05x0.95mm_HandSolder
D3: LTST-C190EKT; LED_0603_1608Metric_Pad1.05x0.95mm_HandSolder
H1, H2: MountingHole; MountingHole_3.2mm_M3
J1: Conn_01x06; CastellatedHole_1x06_P2.54mm_PinHeaders
J2: USB4125-GF-A; GCT_USB4125-GF-A
J3, J4, J5: Conn_01x03; CastellatedHole_1x03_P2.54mm_PinHeader
Q1: IRF9358PbF; HSOP-8-1EP_3.9x4.9mm_P1.27mm_EP2.41x3.1mm_ThermalVias
Q2: BSL308PE; SOT-23-6
Q3: NTR4503N; SOT-23-3
R1, R5: 49.9kΩ; R_0402_1005Metric
R2: 10kΩ; R_0603_1608Metric
R3: 0Ω; R_0402_1005Metric_Pad0.72x0.64mm_HandSolder
R4, R7: 1kΩ; R_0402_1005Metric
R6, R9, R10, R11, R12, R20, R22: 2.2kΩ; R_0805_2012Metric_Pad1.20x1.40mm_HandSolder
R8: 1M; R_0603_1608Metric_Pad0.98x0.95mm_HandSolder; not fitted
R13: 1kΩ; R_0402_1005Metric_Pad0.72x0.64mm_HandSolder
R14, R16, R21: 5.1kΩ; R_0805_2012Metric_Pad1.20x1.40mm_HandSolder
R15, R17, R19: 5.1kΩ; R_0805_2012Metric_Pad1.20x1.40mm_HandSolder; not fitted
R18: 49.9kΩ; R_0402_1005Metric_Pad0.72x0.64mm_HandSolder
U1: CYPD3177-24LQXQx; QFN-24-1EP_4x4mm_P0.5mm_EP2.7x2.7mm_ThermalVias

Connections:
+1V8: C1.1, J3.2, U1.24 (VCCD)
+3V3: C2.1, C3.1, C4.1, J3.1, R9.1, R10.1, R11.1, R12.1, R14.1, R15.1, R16.1, R17.1, U1.23 (VDDD)
/CC1: C10.1, J2.A5 (CC1), U1.15 (CC1)
/CC2: C11.1, J2.B5 (CC2), U1.14 (CC2)
/DC_{OUT}: C9.1, J1.1, J1.2, Q1.3, U1.11 (VDC_OUT)
/FAULT: J5.3, Q3.2 (G), R18.1, U1.9 (FAULT)
/FET_{Gate}: D1.2 (A), Q1.2, Q1.4, R1.2, R3.1
/FET_{SRC}: D1.1 (K), Q1.1, Q1.5, Q1.6, R1.1
/FLIP: J5.2, R9.2, U1.10 (FLIP)
/GPIO: J5.1, U1.8 (GPIO_1)
/I_{Sink, Coarse}: R16.2, R21.1, U1.5 (ISNK_COARSE)
/I_{Sink, Fine}: R17.2, R22.1, U1.6 (ISNK_FINE)
/SCL: J4.1, R12.2, U1.13 (HPI_SCL)
/SDA: J4.2, R11.2, U1.12 (HPI_SDA)
/Safe-5V_{OUT}: J1.5, J1.6, Q2.2
/Shield: C12.1, J2.S1 (SHIELD), R8.1
/VBUS: C5.1, C6.1, C7.1, C8.1, D3.2 (A), J2.A9 (VBUS), J2.B9 (VBUS), Q1.7, Q1.8, Q2.6, R2.1, R5.1, R6.1, U1.18 (VBUS_IN)
/VBUS_{MAX}: R14.2, R19.1, U1.2 (VBUS_MAX)
/VBUS_{MIN}: R15.2, R20.1, U1.1 (VBUS_MIN)
/~INT: J4.3, R10.2, U1.7 (HPI_INT)
GND: C1.2, C2.2, C3.2, C4.2, C5.2, C6.2, C7.2, C10.2, C11.2, C12.2, D2.1 (K), J1.3, J1.4, J2.A12 (GND), J2.B12 (GND), J3.3, Q1.9, Q3.3 (S), R8.2, R18.2, R19.2, R20.2, R21.2, R22.2, U1.19 (GND), U1.22 (VSS), U1.25 (EPAD)
unnamed: C8.2, C9.2, R2.2, R3.2, R4.1
unnamed: D2.2 (A), R6.2
unnamed: D3.1 (K), R13.1
unnamed: Q2.1, Q2.3, R5.2, R7.1
unnamed: Q2.4, Q2.5
unnamed: Q3.1 (D), R13.2
unnamed: R7.2, U1.4 (SAFE_PWR_EN)
unnamed: R4.2, U1.3 (VBUS_FET_EN)

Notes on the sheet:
FLIP pin (is open drain: 0 or High-Z): (a) FLIP = 0 when Type-C Plug is upside-up (b) FLIP = 1 when Type-C Plug is upside-down FAULT pin goes HIGH when: (a) Power adapter does not advertise compatible PDOs (b) VBUS is out of (VBUS_{MIN}, VBUS_{MAX}) range HPI pins (I2C Slave at address 0x08) can be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
NOTE: Safe-5V_{OUT} is turned on when a suitable set of PDOs are not available and VBUS falls back to 5V
5.1kΩ
Clamp V_{GS} to 10V absolute
1/6
Pull-Down
Pull-Up
0.9A
I_{Sink, Fine}
* When pullup-pulldown combination is 0-none or none-0, use any resistor instead of 0-ohm
1kΩ
10kΩ
+3V3 Ratio
2.4kΩ
VBUS_{MIN}
>5/6
4/6
Fine Current
0kΩ*
open
0.75A
3/6
19V
2/6
VBUS_{MAX}
0/6
0.25A
Req. Voltage
20V
I_{Sink, Coarse}
12V
Coarse Current
15V
0.5A

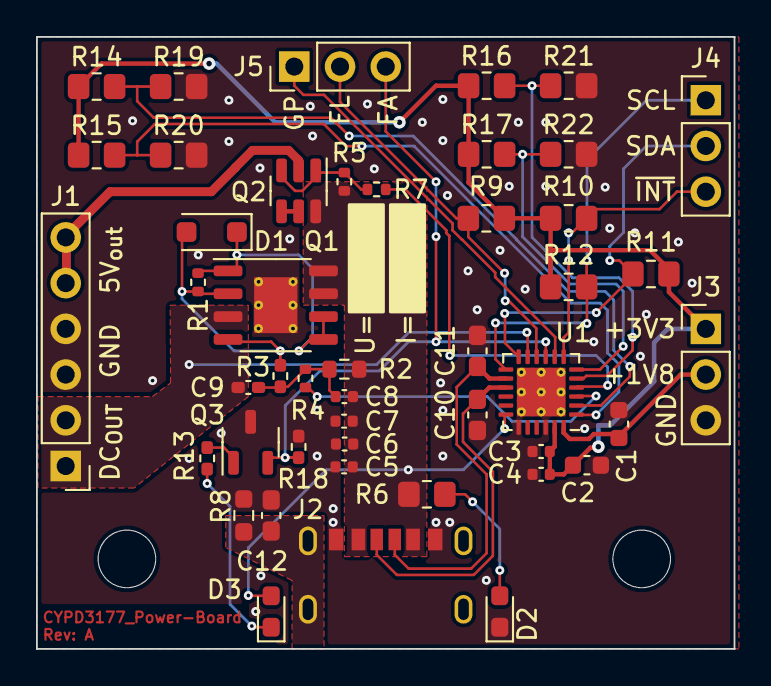
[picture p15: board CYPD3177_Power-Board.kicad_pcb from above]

Board: 2 copper layers, 38.8 x 34.0 mm, 49 parts (0 on the bottom side), 29 nets.

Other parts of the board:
G0: LOGO; elektronik-emblem_3x3.5_solder

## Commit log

2023-05-19 Add: Default project from template
    [CYPD3177_Power-Board.kicad_pcb, CYPD3177_Power-Board.kicad_sch]
2023-05-19 Add: InfineonData for the CY4533, an evaluation platform with the CYPD3177
    [121-60538-01_CY4533_BCR_EVK_PCBA_BOM.xlsm]
2023-05-19 Add: Initialized schematic, used the Infineon-CY4533_Guide-UserManual as a guide
    [CYPD3177_Power-Board.kicad_sch]
2023-05-20 Mod: Schematic, modified some resistor value to not use as much; Add: Description texts and tables
    [CYPD3177_Power-Board.kicad_sch]
2023-05-20 Mod: Power connector and changed date
    [CYPD3177_Power-Board.kicad_sch]
2023-05-20 Mod: Assigned all footprints, without the connectors
    [CYPD3177_Power-Board.kicad_sch]
2023-05-20 Add: Footprint for the connectors (castellated holes) and mounting holes
    [CYPD3177_Power-Board.kicad_sch]
2023-05-23 Mod: Footpints and changes order of the power outputs on J1
    [CYPD3177_Power-Board.kicad_sch]
2023-05-23 Mod: PCB, placed components, draw board shape and placed a few traces
    [CYPD3177_Power-Board.kicad_pcb, CYPD3177_Power-Board.kicad_sch]
2023-05-26 Mod: Moved voltage dividers and placed all traces
    [CYPD3177_Power-Board.kicad_pcb]
2023-05-28 Mod: PCB, last touches, moved logo, added some more vias and some pin labels
    [CYPD3177_Power-Board.kicad_pcb]
2023-05-28 Add: Dimensions and moved holes and castellated holes
    [CYPD3177_Power-Board.kicad_pcb]
2023-05-28 Mod: PCB, removed all errors, for that the castellated holes, the USB connector and more had to be adjusted
    [CYPD3177_Power-Board.kicad_pcb]
2023-05-28 Add: Parts from LCSC
    [CYPD3177_Power-Board.kicad_pcb, CYPD3177_Power-Board.kicad_sch]
2023-05-29 Mod: Corrected the pin alignment so that the possible pin header would be on the same 2.54mm grid
    [CYPD3177_Power-Board.kicad_pcb]
2023-05-29 Mod: Changed castellated holes to pin headers because they are cheapter
    [CYPD3177_Power-Board.kicad_pcb]
2023-05-29 Mod: Changed thermal pad of Q1 to the GND plane
    [CYPD3177_Power-Board.kicad_pcb]
2023-05-29 Add: LCSC part nr. to the scheme and added designator U1 to the PCB
    [BOM-CYPD3177_Power-Board.csv, CYPD3177_Power-Board.kicad_pcb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]
2023-06-14 Dbug: Schematic, changed the connection between the two MOSFETs in both of the output FETs (Q1, Q2)
2023-06-20 Mod: Schematic and database, changed LCSC part number of R3
    [CYPD3177_Power-Board.kicad_sch]
